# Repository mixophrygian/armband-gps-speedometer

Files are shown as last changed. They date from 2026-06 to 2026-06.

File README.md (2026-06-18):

# Armband GPS Speedometer

A kid-wearable armband speedometer built from Adafruit modules:

- GPS speed from an Adafruit Mini GPS PA1010D.
- mph (2 decimals) on a 4-digit seven-segment FeatherWing.
- A single 10-pixel NeoPixel lane on the armband (scoped down from the original
  four-lane plan; the armband only has room for ~10 pixels at 60 LED/m).
- Electronics pod hardwired to the lane, charged in place via USB-C through the
  Feather RP2040 (no pod-to-armband connector).

This v1 intentionally avoids a custom PCB. It uses existing Adafruit boards and
a small soldered perma-proto wiring hub inside the pod. Do not use a solderless
breadboard in the wearable.

## Project Structure

- `CIRCUITPY/code.py` - firmware to copy onto the Feather's CIRCUITPY drive.
- `CIRCUITPY/bringup/` - staged test programs to copy as `code.py` during
  bench bring-up.
- `CIRCUITPY/lib/requirements.txt` - CircuitPython libraries to copy into
  `CIRCUITPY/lib/`.
- `docs/bom.md` - purchase list and missing-part traps.
- `docs/bench-bringup.md` - detailed first-power, header, display, GPS,
  battery, and LED bring-up instructions.
- `docs/wiring.md` - electrical wiring, LED lane, and charging switch.
- `docs/assembly-checklist.md` - build phases from bench to final armband.
- `docs/3d-printing-guide.md` - primary enclosure walkthrough for the
  3D-printed pod (OpenSCAD, slicing for Bambu/Prusa, PETG, print order).
- `cad/enclosure.scad` - parametric 3D-printable enclosure (compact, battery
  under the stack for low CoG; ~69 x 61 x 41 mm).
- `cad/verify_fit.py` - optional CAD sanity check that redraws the plan view.
- `docs/test-plan.md` - bench and field acceptance tests.

## Firmware Defaults

- Units: mph.
- Display: speed in mph, 2 decimals (auto-drops to 1 decimal at/above 100 mph to fit 4 digits).
- LED lanes: 1.
- Pixels per lane: 10.
- Total pixels: 10.
- LED pin: Feather `D6`.
- LED brightness cap: `0.12`.
- LED lane wiring: single straight lane, no serpentine. (The firmware keeps the
  lane/`LANE_REVERSED` scaffolding so a future multi-lane build only needs the
  constants in `code.py` changed.)

## Install

Start with `docs/bench-bringup.md`; it walks through Feather setup, header
soldering, display installation, GPS, battery charging, and LED tests in order.

Quick install summary:

1. Install CircuitPython for the Adafruit Feather RP2040.
2. Copy `CIRCUITPY/code.py` to the CIRCUITPY drive as `code.py`.
3. Copy the required libraries from the Adafruit CircuitPython Library Bundle
   into `CIRCUITPY/lib/`: `adafruit_gps`, `adafruit_ht16k33`, and `neopixel`.
   If using `circup`, run `circup install -r CIRCUITPY/lib/requirements.txt`
   from this project folder after the Feather is mounted.
4. Wire the hardware following `docs/wiring.md`.
5. Run the bench tests in `docs/test-plan.md` before enclosing anything.

The firmware is designed to be useful during bring-up: it shows `8888` and a
blue sweep on boot, `----` plus an amber wave while waiting for GPS, speed
(2-decimal mph) plus a fixed-rate rainbow comet once GPS data is available, a
yellow pulse plus `----` if a fix goes stale/lost, and `Err` plus red flashing
for caught application errors after hardware setup.

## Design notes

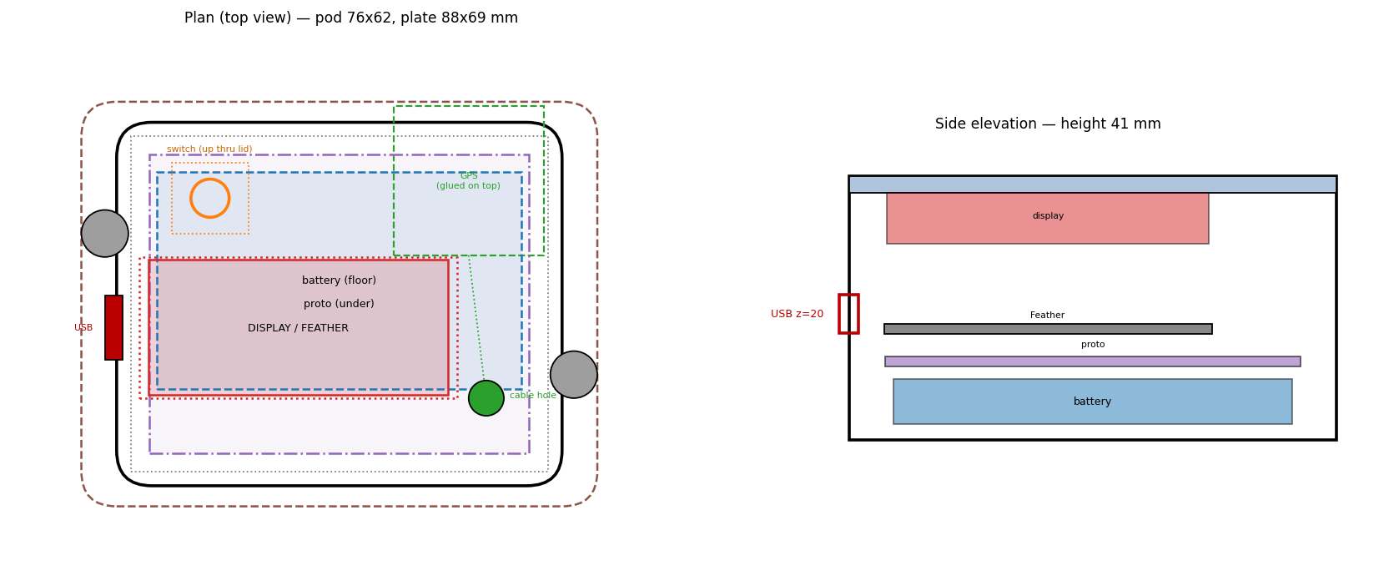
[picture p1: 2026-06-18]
cad/enclosure_plan.png

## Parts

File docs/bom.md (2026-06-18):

# Bill of Materials

This is the complete shopping list to build one armband speedometer from
scratch. Adafruit PIDs are given where a specific part matters; equivalents from
other vendors work unless a note says otherwise.

## Core Electronics

| Qty | Item | Notes |
| --- | --- | --- |
| 1 | [Adafruit Feather RP2040, PID 4884](https://www.adafruit.com/product/4884) | Main controller, USB-C, built-in LiPo charger, STEMMA QT. |
| 1 | [Adafruit Mini GPS PA1010D STEMMA QT, PID 4415](https://www.adafruit.com/product/4415) | Mount antenna facing skyward, not under the display/battery. |
| 1 | [Adafruit 0.56" 4-Digit 7-Segment FeatherWing, PID 3108 (red) or 3110 (yellow)](https://www.adafruit.com/product/3108) | Yellow (3110) is a bit more readable in bright daylight; red (3108) is fine indoors/dusk. Either works. |
| 1 | [Adafruit Lithium Ion Battery 3.7V 2000mAh, PID 2011](https://www.adafruit.com/product/2011) | Documented battery for this build and the 3D-printed enclosure. Adafruit-standard JST-PH polarity, built-in protection circuit, 60 x 36 x 7 mm. **Still verify connector polarity against the Feather silkscreen before first power (see bench-bringup.md Stage 6).** |
| 1 | [STEMMA QT / Qwiic JST-SH 4-pin I2C cable](https://www.adafruit.com/product/4399) | Connects the GPS to the Feather. |

## LED Lane

| Qty | Item | Notes |
| --- | --- | --- |
| 1 m | BTF-LIGHTING WS2812B Pure Gold Wire LED Strip, 60 LED/m, IP65, black PCB (Amazon) | The build uses 10 pixels (1 lane); 1 m (60 px) is plenty and leaves practice/splice scraps. WS2812B = standard NeoPixel chip; Pure Gold Wire = premium bond-wire variant (more reliable than the ECO line) for a wearable that takes abuse. See [LED Strip Details](#led-strip-details) below. |

## Headers & Power Conditioning

| Qty | Item | Notes |
| --- | --- | --- |
| 1 | Feather stacking headers | Must be stacking-style: female sockets on top, male tails extending below the Feather. Plain male strips won't give the under-side access the wiring needs. |
| 1+ | Male header strip | For the 7-segment FeatherWing legs. |
| 1 | 470 ohm resistor | NeoPixel data line. Anything 300-500 ohm is fine; a single 330 ohm works too. |
| 1 | 100uF electrolytic capacitor, 6.3V+ | Place near the first LED on the armband side, not the pod-side connector. 100uF (vs the usual ~1000uF) is deliberate here: LiPo source, brightness capped at 0.12, only 10 px = tiny transients. See wiring.md. |
| 1 | Miniature DPDT switch — 6mm-bushing **toggle** | One pole disables Feather `EN`; one pole cuts LED `BAT+`. The 3D enclosure cuts a 6.5mm round hole + guard ribs for the toggle. |

## Wiring & Assembly

| Qty | Item | Notes |
| --- | --- | --- |
| 1 | **Half-size** perma-proto (51 x 81 mm), or generic perfboard | Pod wiring hub. A quarter-size board doesn't have enough holes to seat the Feather — use half-size [PID 1609](https://www.adafruit.com/product/1609). Trim to ~65 x 51 to fit the enclosure (cut the length only; this board sizes the box). |
| Several | 26-30AWG silicone stranded wire | Red, black, and a third color for data. |
| Several | Heat-shrink tubing | Cover every soldered LED-strip joint. |
| Several | Standoffs/screws or foam tape | Secure boards inside the pod. |
| 1 | USB-C data cable | Must transfer data, not just charge. |

## Mechanical / Enclosure

| Qty | Item | Notes |
| --- | --- | --- |
| 1 | Armband | Any wearable band; the LED lane is semi-permanently attached to it. |
| 1 | 3D-printed pod/enclosure | Print the parametric enclosure in `cad/` using `docs/3d-printing-guide.md`. |
| Several | Velcro/hook-and-loop patches | Attach the pod to the armband. |
| Several | Flexible fabric/foam backing strips | Prevent sharp bends at LED solder joints. |
| Several | Cable tie points, thread, or adhesive | Strain relief at the pod-to-lane cable and LED lane ends. |

## Optional

| Qty | Item | Notes |
| --- | --- | --- |
| 1 | CR1220 coin cell | Improves GPS warm-start time. Not required. |

## Tools

| Item | Notes |
| --- | --- |
| Soldering iron + solder | Headers, LED-strip joints, and perma-proto wiring. |
| Multimeter | Required for the battery polarity check (bench-bringup.md Stage 6); also useful for continuity / short checks throughout. |
| Wire cutters / strippers | For the silicone wire and LED-strip leads. |

## LED Strip Details

**BTF-LIGHTING WS2812B Pure Gold Wire LED Strip Light**, 60 LED/m, IP65, black
PCB.

Build allocation:

- 10 pixels in service (1 lane x 10 pixels, lane ~167 mm / 6.6 in) — the armband
  only fits ~10 pixels at 60 LED/m
- The rest of a 1m strip (50 px) is practice scraps and splice spares

Why these specifics:

- **WS2812B chip** is the Adafruit `neopixel` library's reference part. No
  protocol surprises.
- **Pure Gold Wire** is BTF-LIGHTING's premium line. Pure-gold bond wires
  inside each LED package (vs aluminum or alloy on the ECO line) mean better
  corrosion resistance and longer-term reliability — relevant for a wearable
  that takes abuse.
- **IP65** silicone front coating adds sweat and scuff resistance. Sewing
  impact is negligible when sewing between LEDs.
- 60 LED/m at 10 px = ~167 mm lane length, fits the usable armband space and
  still gives room for a clean 5-7 px comet tail (8 px is the floor for a
  recognizable comet, so 10 has margin).
- 2000 mAh LiPo (PID 2011) runs the system many hours at brightness 0.12, far
  past the 90-minute runtime target, with only one lane driven.
- WS2812B is nominally 4-7 V; at 3.7 V LiPo it works but you may see slight
  color drift below ~3.4 V battery voltage. Acceptable at brightness 0.12.

Headroom: leftover strip gives you material to scale up later if you find more
armband real estate. To add pixels or lanes, change `PIXELS_PER_LANE` (and
`LANE_COUNT` / `LANE_REVERSED` for multiple lanes) in `CIRCUITPY/code.py`, and
update `PIXEL_COUNT` in `CIRCUITPY/bringup/05_one_lane_neopixel_test.py` to match
what you cut.

## Pre-Buy / Pre-Power Trap Check

- Battery polarity verified against the Feather silkscreen before plugging in,
  with a multimeter? (See `bench-bringup.md` Stage 6.)
- Stacking headers confirmed, not just plain male strips?
- 7-segment LED module is planned to plug into the Feather via stacking
  headers, not soldered directly to the Feather?
- USB-C cable is data-capable, not charge-only?
- Strain relief plan exists for the hardwired pod-to-lane cable (grommet clamp + service slack)?
- 470 ohm resistor and 100 uF cap for NeoPixel data and power?
- Enough heat shrink for all LED-lane and cable solder joints?
- Way to see the Feather charge LED after the pod is assembled?

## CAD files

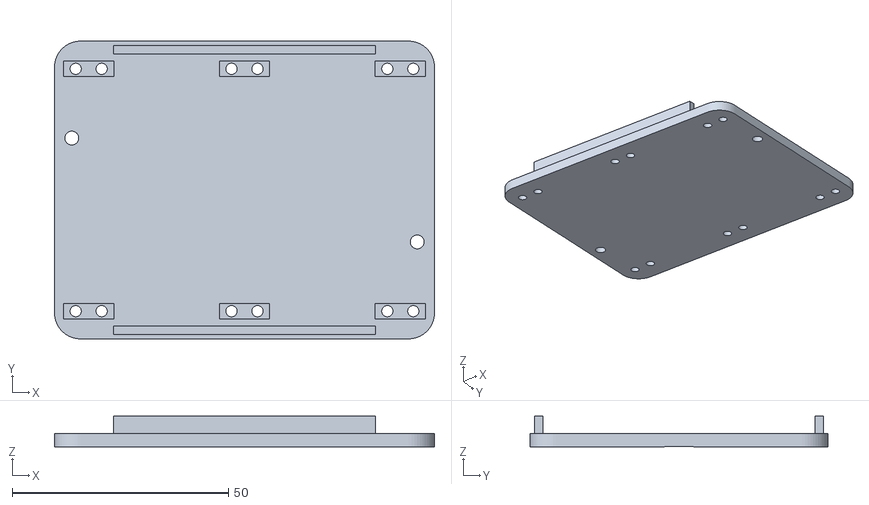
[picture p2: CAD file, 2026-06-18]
cad/base_plate.stl
87.8 x 68.8 x 7.06

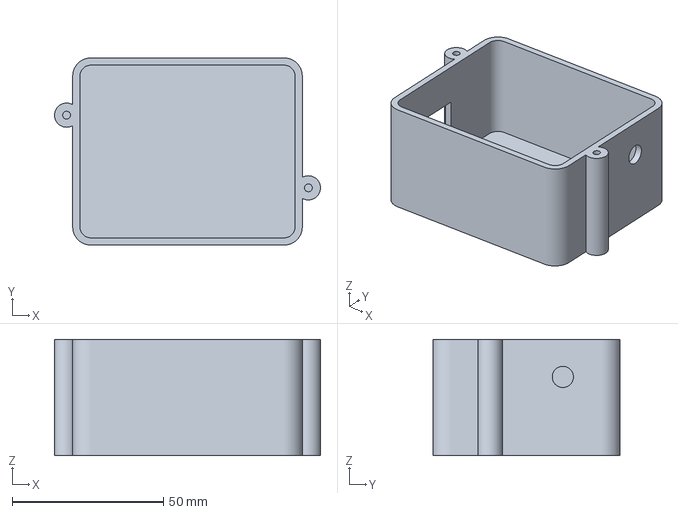
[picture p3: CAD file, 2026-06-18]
cad/base.3mf
87.8 x 61.8 x 38.4 mm

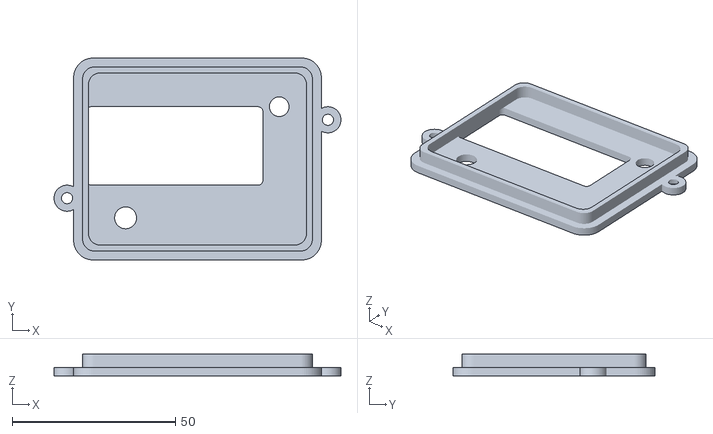
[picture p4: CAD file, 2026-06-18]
cad/lid_print.stl
87.8 x 61.8 x 6.60

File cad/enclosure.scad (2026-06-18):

// ============================================================================
//  Armband GPS Speedometer  —  Enclosure  (parametric)  —  v2: COMPACT
//  Battery sits on the floor UNDER the Feather (lowest centre of gravity).
//  All units are MILLIMETRES.
// ----------------------------------------------------------------------------
//  HOW TO USE (OpenSCAD):
//    F5 = preview | F6 = render | export STL via File > Export
//    Choose what to show with `part` below. Watch the console: it ECHOes the
//    battery clearance and the computed USB cutout height every render.
//
//  Vertical stack-up, floor -> sky (per your assembly):
//    floor -> [LiPo 7mm, flat on the floor] -> small gap -> PERMA-PROTO
//    (the Feather's header tails plug DOWN into it) -> Feather (sits close above
//    the proto) -> stacking-header gap -> FeatherWing backpack -> 7-seg display
//    (face seats against the lid window). display+Feather+proto hang from the lid
//    as ONE plugged-together unit; the battery sits on the floor beneath them.
//    The half-size perma-proto (51 x 81) is far too LONG for this box (81 > 64),
//    so it's TRIMMED to a small hub (proto_l/proto_w) that fits under the Feather.
//    Still MEASURE the assembled drop (display face -> proto bottom) to confirm
//    the height - that's the one number specs can't give you.
//
//  Companion guide: docs/3d-printing-guide.md
// ============================================================================


// ============================================================================
//  WHAT TO RENDER / EXPORT  (one part at a time; export each as its own STL)
// ============================================================================
part = "base";   // "base" | "lid" | "lid_print" | "baseplate" | "assembled"
mount_features = false;   // false = plain box (print this FIRST); true = add posts/cradle
$fn = 56;


// ============================================================================
//  MEASURED PARTS  —  values are your Adafruit spec sheets. (VERIFY) = confirm.
// ============================================================================

// --- Feather RP2040 + 7-seg FeatherWing stack (tallest assembly) ------------
feather_l        = 51.0;   // Feather 51.0 x 23.0 x 7.5
feather_w        = 23.0;
stack_hang       = 22.0;   // display face (at lid) -> Feather PCB bottom   << MEASURE
stack_envelope   = 27.0;   // display face -> tail tips, TRIMMED tails      << MEASURE
                           //   (was ~29 untrimmed; trimming flush after wiring is
                           //    what gets the box to ~41mm. Don't trim -> set back
                           //    to ~29 and bump inner_h ~4mm.)
feather_hole_dl  = 45.72;  // Feather mount-hole spacing, lengthwise  (VERIFY)
feather_hole_dw  = 17.78;  // Feather mount-hole spacing, widthwise   (VERIFY)
//  stack_hang and stack_envelope set the box HEIGHT and the USB cutout height,
//  and they depend on your stacking headers + how far the display stands off
//  the backpack + how you trim the tails -- none of which is on a spec sheet.
//  So MEASURE the assembled stack: face->Feather-PCB, and face->tail-tips.
//  Defaults here are a conservative estimate (display standoff ~10, header gap
//  ~8.5, tails ~7.5). Trimming the tails drops stack_envelope ~4mm; shave inner_h.

// --- 0.56" 4-digit 7-seg display --------------------------------------------
disp_pkg_l       = 50.0;   // display face length   (MEASURE your part)
disp_pkg_w       = 20.0;   // display face height    (you measured ~20, spec said 19)
disp_lip         = -2.0;   // NEGATIVE = clearance. -2 => window is 4mm bigger than the
                           //   display (2mm slop all round), so a recessed display
                           //   shows through with a small border and needs no precise
                           //   alignment. (Use 0 for a tight flush fit, +1 for a lip.)

// --- Mini GPS PA1010D (PID 4415)  25.5 x 25.4 x 8.2 -------------------------
gps_pcb_l        = 25.5;
gps_pcb_w        = 25.4;
gps_ant_l        = 11.0;   // ceramic patch antenna footprint  (VERIFY!)
gps_ant_w        = 11.0;   // antenna pokes UP through a hole this size

// --- LiPo 2000 mAh (PID 2011)  60 x 36 x 7,  lies FLAT on the floor ---------
batt_l           = 62.0;   // sets the box LENGTH
batt_w           = 37.0;
batt_h           = 7.0;

// --- Perma-proto wiring hub (TRIMMED from a half-size 51 x 81 board) ---------
//  Half-size because the quarter board hadn't enough holes. The hub must seat
//  the WHOLE Feather AND give spare rows to wire in the switch + LED strip, so
//  it's 65 x 51 (cut only the 81mm length down to 65; width left uncut at ~51).
//  This board now DRIVES the box length AND width - see inner_l / inner_w.
//  Reference dims for the fit check (verify_fit.py); the proto isn't printed.
proto_l          = 65.0;   // length, cut down from the stock 81
proto_w          = 51.0;   // width, left at the stock 51 (uncut)

// --- Ports (sizes; positions are in LAYOUT / GEOMETRY) ----------------------
usb_w            = 15.0;   // USB-C cutout width  - oversized for position slop
usb_h            = 10.0;   // USB-C cutout height - oversized in case usb_z is off
led_d            = 3.0;    // charge-LED hole / light pipe
grommet_d        = 7.0;    // armband-cable grommet
//  SWITCH: your part is a TOGGLE with a 6mm threaded bushing (6-pin DPDT),
//  NOT a slide switch. So the cutout is a ROUND hole + nut, not a slot.
//  Body ~13(w) x 12(deep) x 10(tall) sits INSIDE the box; lever sticks OUT.
switch_hole_d    = 6.7;   // 6mm thread + clearance (some are 1/4" -> try 6.7)


// ============================================================================
//  ENCLOSURE SHELL
// ============================================================================
inner_l   = 71;    // now set by the 65mm trimmed proto + end slack (the proto is
                   //   the longest thing in the box, not the 60mm battery)
inner_w   = 57;    // holds the 51mm-wide proto hub (centred) with margin
inner_h   = 36;    // ~41mm external. ASSUMES trimmed tails (see stack_envelope).
                   //   battery(7) + proto(2) + stack(25) + clearance(2).
//  L and W are now driven by the wiring hub: it has to seat the whole Feather
//  PLUS spare rows for the switch + LED-strip wiring, so it's 65 x 51.
//  Height is still set by the vertical stack + battery underneath (CoG stays low).

wall      = 2.4;
floor     = 2.4;
lid_th    = 2.6;
corner_r  = 6.0;

// --- lid <-> base mating -----------------------------------------------------
lip_h     = 4.0;
lip_th    = 1.8;
lip_clear = 0.35;

// --- EXTERNAL screw ears (2x, short ends) ------------------------------------
ear_r          = 4.0;
ear_overlap    = 2.0;
ear_pilot_d    = 2.6;
ear_clear_d    = 3.4;
ear_head_d     = 6.2;
ear_head_h     = 2.2;

// --- printed internal mounts (only when mount_features = true) ---------------
post_od        = 5.0;
post_pilot_d   = 2.2;
cradle_wall    = 2.0;
cradle_clear   = 1.0;
cradle_h       = 5.0;

// --- mounting baseplate (separate part: pod-size, sewn on, NO outboard flange)
show_mount     = true;   // draw the baseplate under the pod in the "assembled" view
plate_th       = 3.0;    // plate thickness
mount_radius   = 10000;  // DEFAULT FLAT for printing. A concave dish only touches
                         //   the bed at its rim and FAILS mid-print, so print the
                         //   plate flat and curve it to the brace by HEAT-FORMING
                         //   (heat gun till floppy, press onto the brace, hold to
                         //   cool). Only set a real radius (e.g. 120) if you truly
                         //   intend to print the curve with supports - not advised.
rail_h         = 4.0;    // locating rails the pod body nests between (anti-rock)
rail_t         = 2.0;
mount_screw_d  = 3.2;    // M3 up into the pod's end ears (uses the bottom pilots)
// thread anchors (sew the plate to the brace; no outboard flange needed):
anchor_hole_d  = 2.6;    // pair of these per anchor - sew up one, down the other
anchor_gap     = 6.0;    // hole spacing within a pair
groove_w       = 3.5;    // top groove the thread loop recesses into (pod won't pinch it)
groove_depth   = 1.4;    // leaves ~1.6mm bridge under the thread - don't go deeper
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

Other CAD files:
cad/base.stl

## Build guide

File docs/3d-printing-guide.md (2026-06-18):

# 3D Printing the Enclosure — From Zero

You've never printed anything, so this starts at the beginning and stays applied:
every step is tied to producing *this* box. The CAD file is `cad/enclosure.scad`.

## The one mental model to start with

A 3D print goes through **three** programs, not one. People new to it usually
think "CAD file → printer" and get stuck when the printer won't open their file.

1. **Design (CAD)** — you make the shape. That's `enclosure.scad`, opened in
   OpenSCAD. Output: an **STL** file (a watertight mesh of the shape).
2. **Slice** — separate software (Bambu Studio / Orca for the Bambu, PrusaSlicer
   for the Prusa) chops the STL into layers and writes machine instructions
   (**G-code / .3mf**) for *your specific printer and filament*.
3. **Print** — the printer runs the sliced file.

CAD knows nothing about your printer; the slicer is where printer- and
material-specific reality enters. Keep these three buckets separate in your head
and nothing about this will be confusing.

---

## Part 1 — OpenSCAD: see the box, then bend it to your parts

### Install and first render (Mac)

1. Download OpenSCAD from `openscad.org/downloads.html`, drag to Applications.
   (Free, ~40 MB. Windows/Linux builds are on the same page.)
2. Open `cad/enclosure.scad` in it. You'll see code on the left, a 3D view on
   the right.
3. Press **F5** (Preview — fast). The box appears. Drag to orbit, scroll to zoom.
4. At the top of the file, change `part = "assembled"` to `"base"`, press **F5**
   again. Now you see just the shell. Try `"lid"`. This is how you'll look at
   each piece.

That's the whole interaction loop: **edit a number → F5 → look**. OpenSCAD is
"CAD by typing," which sounds backwards but is exactly why it's the right tool
here — every dimension is a labeled variable, so making the box fit your parts is
editing numbers, not nudging geometry with a mouse.

### Design at a glance (the compact layout)

The box is **~69 × 61 × 41 mm** (plus two small screw ears on the ends). It's
**layered**: the display (centred) and GPS live at the lid; below them the column
is **battery → perma-proto → Feather → display**, with the battery flat on the
floor. That keeps the heaviest part lowest (low centre of gravity on your arm).
Reaching ~41 mm tall assumes you **trim the stacking-header tails** after wiring
and **trim the half-size perma-proto** to a small hub.

Two things to know:

- **GPS over the battery — mostly a non-issue here.** The battery overlaps the
  GPS in plan, but it sits ~28 mm *below* the lid-mounted antenna — about a patch
  antenna's near-field edge (λ/2π ≈ 30 mm at L1), with the GPS's own ground plane
  in between. That vertical gap does the real work, so expect at most a minor
  effect, not a meaningful sensitivity loss (and the battery is passive metal,
  not an RF noise source). On an arm-worn device the body under the antenna is a
  bigger lower-side RF load than the battery anyway. If you ever want more GPS
  margin, the real lever is a larger ground plane under the patch (copper tape to
  GND) — the PA1010D's weak point — not relocating the battery.
- **Want it even smaller?** Three levers: a shorter battery (the 60 mm cell sets
  the box length), trimming the stacking-header tails after wiring (shaves
  height), and cutting the perma-proto hub down to a small perfboard scrap so it
  tucks into dead space instead of needing its own room.

### How the file is built (so you can change it)

Open the file and read top to bottom — it's commented for exactly this. The
structure:

- **`MEASURED PARTS`** — real-world sizes (Feather, display, GPS antenna,
  battery). These came from the documented parts in `docs/bom.md`. Several
  are marked **`(VERIFY)`** — those are the ones I'm least sure of and you must
  confirm with calipers.
- **`ENCLOSURE SHELL`** — cavity size and wall thicknesses. The cavity
  (`inner_l/w/h`) is the empty space your parts live in; the outer size follows
  automatically.
- **`LAYOUT`** — an X/Y coordinate for each part (where it sits when you look
  down at the lid). These are the numbers you'll nudge after a dry-fit.
- **`GEOMETRY`** — the actual modeling. You rarely touch this.

The load-bearing idea: **you do not redraw anything to refit a part.** Measure
your real battery, type its true length into `batt_l`, press F5. If it now pokes
out of the cavity, bump `inner_w`. That feedback loop is the entire skill.

### Check the fit without printing

`cad/verify_fit.py` is an optional sanity check that mirrors the same numbers
and redraws the top-view plan (`cad/enclosure_plan.png`). Run it after you
change dimensions if you want a quick text/plan check before printing:

```
python3 cad/verify_fit.py
```

It already caught two layout bugs while I was setting this up (the GPS was
clipping the wall and overlapping the display stack). The printed parts and
actual dry-fit are still the real gate. If you change a number in the `.scad`,
update the matching value at the top of `verify_fit.py` before relying on its
output.

### Export the STL

For each part you want to print: set `part` (e.g. `"base"`), press **F6** (full
render — slower, makes it watertight), then **File → Export → Export as STL**.
For the lid, use **`part = "lid_print"`** — that's the lid pre-flipped so its
flat face is down, ready to slice. Export `base.stl` and `lid.stl`.

---

## Part 2 — The order that saves you a wasted print

Do **not** print the fully-featured version first. The internal mounts (printed
Feather posts, battery cradle, GPS retainer) depend on exact part positions you
haven't dry-fit yet. Sequence:

1. **Leave `mount_features = false`** (it already is). Export and print the
   **base only** first — it's the cheapest way to learn your printer and confirm
   the cavity swallows your boards.
2. **Dry-fit.** Drop your actual Feather stack, GPS, and battery into the printed
   base. Confirm they fit with room for wiring. Measure anything that's off with
   calipers and update the `.scad`.
3. **Print the lid** (`part = "lid_print"`), still plain. Check the display
   window lines up with the display face and the GPS antenna pokes through its
   hole. Adjust `stack_x/stack_y` and `gps_x/gps_y` if not.
4. **Now set `mount_features = true`**, tune the mount positions to your dry-fit,
   optionally re-run `verify_fit.py`, and reprint the lid. The base rarely needs
   a reprint.

This is the difference between "print once, glue everything, done in an evening"
(totally fine — you said so) and "print, dry-fit, refine." Start with #1
regardless; it's your real first print and a throwaway is cheap insurance.

A zero-cost version of the dry-fit: print the plan (`cad/enclosure_plan.png`) at
100% scale on paper, lay your parts on it, and check before you print anything.

---

## Part 3 — Slicing (Bambu and Prusa)

You have both a Bambu Lab and a Prusa — both are excellent and both run PETG out
of the box. Pick whichever's free; the steps are the same shape.

**Bambu Lab** → Bambu Studio (or Orca Slicer). **Prusa** → PrusaSlicer.

1. **Open the slicer, pick your exact printer model and nozzle** (almost always
   0.4 mm) from its dropdown. This is the step that makes the file printer-correct.
2. **Import** `base.stl` (and later `lid.stl`). It drops onto the virtual plate.
3. **Orientation** — this matters more than any setting:
   - **Base:** floor flat on the plate, opening up. Import orientation is already
     correct. The walls print upward; the USB/switch cutouts are holes in
     vertical walls and bridge fine with no support.
   - **Lid:** flat outer face **down** on the plate, mount features pointing up.
     If you exported with `part = "lid_print"` it's already oriented; otherwise
     rotate 180° about X. Printed this way the lid needs **no supports**.
4. **Filament:** select a **PETG** profile (e.g. "Generic PETG" or the Bambu/Prusa
   PETG preset). Don't use the default PLA profile.
5. **Key settings** (the presets are mostly right; sanity-check these):
   - Layer height **0.2 mm** (0.28 for the fit-test base if you want it faster).
   - Walls/perimeters **3+** — it's a wearable that gets dropped.
   - Infill **15–20%**, grid or gyroid.
   - Supports **off** (with the orientations above you don't need them).
   - **Brim 3–5 mm** — PETG can lift at the corners; a brim prevents it and peels
     off after. Cheap insurance on a ~70 mm-long flat part.
6. **Slice**, eyeball the layer preview, then **send to the printer** (Bambu: over
   network/SD; Prusa: export G-code to SD/USB).

---

## Part 4 — PETG and the actual print

**Why PETG, briefly:** the default everyone starts with is PLA, which goes soft
around 55–60 °C. A car in summer sun hits that and your box deforms. PETG stays
solid to ~80 °C and shrugs off sweat, UV, and impact — the right call for an
outdoor kid's wearable. It's the second most common filament after PLA: every
spool vendor stocks it, it's cheap, and both your printers handle it natively.
(ABS/ASA is even tougher but warps and smells while printing — not worth it here.)

**PETG quirks vs PLA, so they don't surprise you:**
- Hotter: nozzle ~235–245 °C, bed ~70–85 °C (let the preset set it).
- Likes a **dry** spool — if it's been open in humid air for months, dry it first
  (printer's built-in dry cycle, or a food dehydrator) or you'll get stringing.
- Sticks to smooth PEI build plates *really* well — a thin swipe of glue stick
  acts as a **release** agent so you don't chip the plate prying parts off.
- A little **stringing** (fine hairs) is normal; they brush off.

**Running it:**
1. Make sure the build plate is clean (IPA wipe) and loaded with PETG.
2. Start the print. **Watch the first layer** — that's where 90% of failures
   happen. It should look like flat, slightly-squished lines fully stuck down,
   no gaps and not see-through. If it's not sticking, stop and re-level / re-set
   Z-offset (your printer's wizard does this).
3. The base is ~1–2 hours; the lid similar. Let the bed cool before removing —
   PETG often pops off on its own as the plate cools.
4. **Post-processing:** the holes may have a thin "bridge" skin or whiskers — open
   them with a hobby knife or a quick twist of a drill bit by hand. Self-tapping
   M3 screws cut their own threads into the bosses; drive slowly so you don't
   strip them.

---

## Print day — taking files to a shared / unknown machine

You don't control the machine, so make the files universal and carry a cheat-sheet.

### Before you leave the house

1. **Plug in your measured numbers and optionally re-run the check.** Open `enclosure.scad`,
   set the `MEASURE`/`VERIFY` values to your real calipered numbers — at minimum
   `stack_hang`, `stack_envelope` (the assembled display→Feather→tail-tips drop),
   `gps_ant_l/w`, and the switch body height. `python3 cad/verify_fit.py` can
   catch obvious layout mistakes, but dry-fitting the real boards is the gate.
2. **Export three STLs.** In OpenSCAD set `part` to each of `base`, `lid_print`,
   and `baseplate`; press **F6**, then **File → Export → Export as STL**.
   - Leave `mount_features = false` for this first round (plain box).
   - For the baseplate's first print, set **`mount_radius = 1000`** so it prints
     **flat** — far easier than a curved plate, and a 3 mm PETG plate pulled down
     by 12 sew/rivet points will conform to a "somewhat curved" stiff brace. Only
     model the real curve if the flat one visibly rocks on the brace.
3. **STL is universal** — it loads in any slicer (Bambu Studio, PrusaSlicer, Cura,
   Orca). You don't need to know the machine in advance.

### What to physically bring

- USB stick with the **3 STLs**, plus a cloud/email copy as backup.
- The **actual electronics** — assembled Feather/display stack, battery, switch —
  to **dry-fit into the base on the spot**. This is the whole point of going: find
  out it fits (or doesn't) before you leave.
- **Calipers.**
- A **PETG spool** if the shop lets you load your own filament; otherwise ask what
  they have. PLA is fine for the *throwaway test base* only — get PETG for the
  real build (see Part 4 for why).
- This guide.

### At the machine (any slicer)

1. Import the STL.
2. Select **the machine's own printer profile** (ask staff which model) and a
   **0.4 mm nozzle**.
3. Filament: **PETG** if available.
4. **Orientation** (this is the part people get wrong):

   | Part | Sits on the bed as | Support |
   | --- | --- | --- |
   | `base` | floor down, opening up (as exported) | none |
   | `lid` (use `lid_print`) | flat outer face down, features up | none |
   | `baseplate` (flat) | flat bottom down, rails up | none |

5. Settings: **0.2 mm** layer, **3** perimeters, **15–20 %** infill, **supports
   OFF**, **brim 5 mm**.
6. Slice, eyeball the preview, and **print the `base` first**.

### Order on the day

Print the **base first** → **dry-fit your boards into it right there** → if it's
good, print the **lid** and **baseplate** in the same session. If something's off,
note exactly what, and it's a one-variable fix back home rather than a bad full
set of prints. Bringing the electronics is what turns one trip into a finished
fit instead of a guess.

---

## When you're back at it

The realistic path: install OpenSCAD, render the box, **print the plain base
first** as your learning print, dry-fit your boards, then refine. Everything
above is reference you can come back to. When you hit the dry-fit step and the
numbers need changing, that's the moment to come back and we'll tune the layout
together.

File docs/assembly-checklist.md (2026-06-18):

# Assembly Checklist

## 1. Pre-Purchase Check

- [ ] All core boards are in the cart: Feather RP2040, PA1010D GPS, 7-segment FeatherWing.
- [ ] NeoPixel strip quantity is 1 m; the build only uses ~10 pixels (~167 mm).
- [ ] LiPo is Adafruit-compatible JST-PH polarity.
- [ ] STEMMA QT cable is present for the GPS.
- [ ] 26-30 AWG silicone wire (red/black/data color) for the hardwired pod-to-lane cable is present. (v2 uses no pod-to-armband connector; the JST-PH 6-pin pairs are spares.)
- [ ] 6mm-bushing DPDT toggle switch is present.
- [ ] Resistor, capacitor, silicone wire, heat shrink, Velcro, foam, and USB-C cable are present.

## 2. Bench Bring-Up

- [ ] Follow `docs/bench-bringup.md` before mounting anything to the armband.
- [ ] Feather alone boots over USB and prints from `01_feather_serial.py`.
- [ ] CircuitPython libraries are installed in `CIRCUITPY/lib/`.
- [ ] 7-segment LED module is soldered to the display FeatherWing in the correct orientation.
- [ ] Display FeatherWing male headers are soldered straight.
- [ ] Feather stacking headers are soldered straight.
- [ ] I2C scan sees display address `0x70`.
- [ ] Display test shows `8888` and a counter.
- [ ] GPS is connected by STEMMA QT; I2C scan sees GPS address `0x10`.
- [ ] GPS test reports fix/satellites outdoors.
- [ ] LiPo charges over Feather USB-C and boots the Feather on battery.
- [ ] The 10-pixel NeoPixel lane works on the bench before bonding to fabric.

## 3. LED Lane Prototype (single 10-pixel lane)

- [ ] Cut one 10-pixel lane.
- [ ] Note the data direction arrow before sewing or bonding; wire into `DIN`.
- [ ] Solder `+`, `GND`, and data (through the 470 ohm resistor) to the `DIN` end.
- [ ] Heat-shrink every exposed LED lane joint.
- [ ] Verify all 10 pixels animate.

## 4. Switch And Charging Test

- [ ] Wire DPDT switch on the bench before final pod assembly.
- [ ] OFF position grounds Feather `EN`.
- [ ] OFF position disconnects LED `+` from Feather `BAT`.
- [ ] ON position leaves Feather `EN` floating and connects LED `+` to Feather `BAT`.
- [ ] LiPo charges from USB-C while the battery remains plugged into the Feather.
- [ ] Charge status LED is visible enough for the final pod design.

## 5. Pod And Armband Dry Fit

- [ ] GPS antenna is skyward and unobstructed.
- [ ] Display is readable while worn.
- [ ] Switch is reachable but not easy to bump accidentally.
- [ ] USB-C is reachable without opening the pod.
- [ ] LiPo is padded and isolated from solder joints.
- [ ] Hardwired pod-to-lane cable is strain-relieved at the pod grommet, with coiled service slack so the lid can lift.
- [ ] Pod Velcros on and off the armband cleanly.
  - Charging method is **finalized: charge-in-place via USB-C** — the whole unit
    stays on the armband while charging, so the pod does not need to come off for
    power. The USB-C port just needs to be reachable through a box opening.

## 6. Final Assembly

- [ ] Permanent wiring is soldered on the proto board. See `proto-soldering.md`
      for the step-by-step solder order (can be done before choosing an enclosure).
- [ ] All exposed joints are heat-shrunk or insulated.
- [ ] Boards are secured with standoffs, screws, or foam tape.
- [ ] Pod corners are rounded or padded.
- [ ] Armband has no scratchy solder, sharp plastic, or loose wire ends.
- [ ] Final firmware settings match the actual pixel count and lane orientation.

## 7. Field Test

- [ ] Outdoor GPS lock succeeds before running.
- [ ] Speed display is readable during movement.
- [ ] LEDs show no-fix, normal, stale/lost, and error patterns.
- [ ] Compare speed against a phone/watch.
- [ ] Check comfort after 10 minutes.
- [ ] Check battery warmth and runtime.

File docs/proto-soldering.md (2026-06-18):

# Proto Board Soldering Walkthrough

This is the bridge between the bench bring-up and the enclosure. You finished
`bench-bringup.md` with everything working on a breadboard with jumper wires.
This doc moves that exact circuit onto a **perma-proto board** as a permanent
wiring hub, using **long wires** so the box can be decided later. Nothing here
forces an enclosure decision.

Read this all the way through before heating the iron.

## The one big idea: a perma-proto is a soldered breadboard

An Adafruit perma-proto has the **same pre-connected layout as a breadboard**:

- Each **row** (the 5 holes on one side of the center channel) is one connected
  node. The two halves of a row are separated by the center channel.
- The strips along the long edges are the `+` and `-` **power rails**.

So the move is simple: **recreate the wiring you already had on the breadboard —
same rows, same rails — and solder it down.** Parts in the same row are already
joined; you only add a wire when two *different* rows (or a row and a rail) need
to connect.

This doc assumes the **half-size** perma-proto with `+`/`-` rails you have. (If
you ever use a plain perfboard with no rails, see the footnote at the end — you
build the rails yourself.)

## What changes and what doesn't

| Part | On the breadboard now | After this doc |
| --- | --- | --- |
| Feather + display stack | tails in breadboard | tails soldered into the perma-proto |
| 470 ohm resistor | breadboard | soldered to the perma-proto |
| DPDT switch | jumpers to breadboard | long wires soldered to the perma-proto |
| LED lane | jumpers to breadboard | hardwired 3-conductor cable soldered to the perma-proto |
| GPS (PA1010D) | STEMMA QT plug | **unchanged — stays a plug into the Feather** |
| LiPo battery | JST-PH plug | **unchanged — stays a plug into the Feather** |
| 100 uF capacitor | (you never installed one) | **optional; if added, on the armband — see `wiring.md`** |

The GPS and battery never touch the perma-proto. They plug into the Feather's own
connectors and stay fully detachable, so the GPS can live outside the box.

## Assumptions (tell me if any are wrong)

1. **Board:** Adafruit perma-proto, half-size, with `+`/`-` rails.
2. **Feather attach:** the Feather's stacking-header **tails are soldered
   directly into the perma-proto rows.** If you want it removable, solder female
   headers in and plug the Feather into those instead — but that adds ~8 mm of
   height, tight in the pod. This doc assumes direct solder.
3. You are using the **470 ohm** data resistor from `bom.md`.

## Tools and materials

- Soldering iron (~350 C / 650 F) with a clean, tinned tip
- Rosin-core solder (60/40 leaded is easiest to learn on; lead-free is fine)
- Flush cutters and wire strippers
- **Stranded silicone wire, 22-26 AWG**, in at least three colors (red `+`,
  black `GND`, a third for data) — cut these **long**, trim later
- A couple of short jumper wires (for row-to-rail hops)
- Heat-shrink tubing + a heat source
- Helping hands or a board vise
- **Multimeter** with continuity (beep) mode — not optional for this

## Soldering primer (read if you've never done this)

- **A good joint:** touch the iron to the pad *and* the lead at the same time for
  ~1 second, then feed solder into the joint (not onto the iron tip). It flows
  and forms a small shiny cone. Solder away, then iron away. ~1-2 seconds total.
- **Cold joint** (dull, blobby, ball sitting on top): reheat, add a touch of
  solder/flux.
- **Bridge** (solder accidentally spanning a row into the next row): wick it off
  or drag it away with the hot tip. Eyeball the underside every few joints.
- Remember the row is *already* connected end to end — you don't need to solder
  every hole in a row, just the one your part/wire sits in.

## The node map (your wiring target)

Six nodes. On a perma-proto a "node" is **a row or a rail**. Keep this next to
you; the final test checks against it.

| Node | What lands on it |
| --- | --- |
| **D6** | Feather `D6` tail + resistor leg 1 (same row = joined) |
| **DATA** | resistor leg 2 + LED cable **data** wire (out to lane `DIN`) |
| **EN** | Feather `EN` tail + switch **pole 1 common** wire |
| **BAT** | Feather `BAT` tail + switch **pole 2 ON-throw** wire |
| **LEDV** | switch **pole 2 common** wire + LED cable **`+`** wire |
| **GND rail** | Feather `GND` tail + switch **pole 1 OFF-throw** wire + LED cable **`GND`** wire |

Switch lugs left **empty**: pole 1 ON-throw and pole 2 OFF-throw.

```text
 row D6   : Feather D6  ===[ 470R ]=== row DATA --> LED cable data --> lane DIN
 row EN   : Feather EN  ------------------------- switch pole1 COMMON
 row BAT  : Feather BAT ------------------------- switch pole2 ON
 row LEDV : switch pole2 COMMON --+--- LED cable + --> lane +
 - rail   : Feather GND --+--- switch pole1 OFF
                          +--- LED cable GND --> lane GND
```

---

## Stage 0: Plan the layout (no soldering)

1. Unplug USB and the LiPo. Set the GPS aside.
2. Dry-fit the Feather (display still stacked) so its two header rows **straddle
   the center channel**, tails into the holes — exactly like on the breadboard.
3. Find the rows its key pins land in: **`D6`, `BAT`, `EN`, `GND`** (the Feather
   pins are silkscreened — `6` is D6). Note them.
4. Pick the **`-` rail** nearest the Feather `GND` row as your GND bus.
5. Pick an empty row next to `D6` for **DATA**, and an empty row for **LEDV**.
6. Plan where the long wires exit (switch wires + the 3-wire LED cable) — toward
   where the cable will leave the future box.
7. Lift the Feather back out. Low-profile parts go in first while the board is
   clear and flat.

Success: you can point to the rows for D6, DATA, EN, BAT, LEDV, and the `-` rail.

## Stage 1: Solder the low-profile parts (Feather out)

1. **Resistor:** bend its legs flat. Put leg 1 in any hole of the **D6 row** and
   leg 2 in the **DATA row**. Solder both, flush-cut the leftover legs. (No
   polarity.) Because the D6 row is one node, the resistor is now joined to
   wherever the D6 tail will land — no extra wire needed.
2. **GND row -> `-` rail jumper:** short wire from any hole of the Feather `GND`
   row to the `-` rail. Solder both ends. Now Feather ground reaches the bus.

Success: resistor bridges D6 row -> DATA row; the GND row beeps to the `-` rail.

## Stage 2: Solder the Feather into the board

1. Reseat the Feather, tails through their rows, straddling the center channel.
   Confirm `D6` lands on the resistor's row and `GND` on the bussed row.
2. **Tack one corner tail,** check the Feather is flat and square, reheat/nudge
   if tilted.
3. Solder the rest of the tails one at a time. At minimum **`D6`, `BAT`, `EN`,
   `GND` plus the four corners** for strength; soldering all that reach holes is
   sturdier. Watch for bridges into neighboring rows.

Success: Feather is rigid, no tilt, no bridged rows.

> The display is stacked on top; soldering the tails underneath won't hurt it.
> Don't dwell on any one pin more than a couple seconds.

## Stage 3: Solder the long switch wires

Cut four wires **long** (reach the switch wherever it lands in the box, plus a
service loop). If the switch already has pigtails from the bench test, solder
their free ends to the board instead.

1. **Pole 1 common -> EN row.**
2. **Pole 1 OFF-throw -> `-` rail.**
3. **Pole 2 common -> LEDV row.**
4. **Pole 2 ON-throw -> BAT row.**
5. Leave pole 1 ON-throw and pole 2 OFF-throw **empty.**
6. Heat-shrink each switch-lug joint so adjacent lugs can't touch.

If unsure which lug is which, redo the common/throw multimeter check from
`bench-bringup.md` Stage 8 before soldering.

Success: four wires run board->switch; two lugs empty; lug joints insulated.

## Stage 4: Solder the hardwired LED cable

The 3-conductor cable that leaves the pod and runs to the armband lane. Cut it
**long** with extra service slack. Colors: red `+`, black `GND`, third = data.

1. **Data wire:** **DATA row** -> lane **`DIN`** pad.
2. **`+` wire:** **LEDV row** (shares the row with the switch pole-2 common wire)
   -> lane **`+`** pad.
3. **`GND` wire:** **`-` rail** -> lane **`GND`** pad.
4. Heat-shrink every joint at the lane end. Strain-relieve the cable at the lane
   end now; the pod-wall strain relief waits for the enclosure.

> A 100 uF cap is optional for this build (you've run fine without one). If you
> add it, it goes across the lane's `+` and `GND` **at the armband**, polarity
> observed — see `wiring.md`. Not on this board.

Success: three wires run board->lane; lane joints insulated and strain-relieved.

## Stage 5: Continuity test before any power

Multimeter on continuity. LiPo and USB disconnected. Check every node connects
and nothing shorts:

- D6 -> resistor -> DATA -> LED data wire: ~470 ohm end to end (not a beep).
- Feather GND -> `-` rail -> switch pole-1 OFF-throw -> LED GND wire: all beep.
- Feather BAT -> switch pole-2 ON-throw: beep.
- Feather EN -> switch pole-1 common: beep.
- LEDV (switch pole-2 common) -> LED `+` wire: beep.
- **Critical short check:** BAT to GND must **NOT** beep (switch ON or OFF).
  LEDV to GND must not beep. D6 to GND must not beep.

Then exercise the switch:
- **ON:** EN to GND should **not** beep (EN floats high = Feather on); BAT to
  LEDV **should** beep (LED power connected).
- **OFF:** EN to GND **should** beep (Feather disabled); BAT to LEDV should
  **not** beep (LED power cut).

Success: every node connects, no power-to-ground short, switch flips both
behaviors. **Do not power up until this passes.**

## Stage 6: Power-up smoke test

1. Plug the GPS back into the Feather's STEMMA QT.
2. Plug in the LiPo, then USB.
3. Same as `bench-bringup.md` Stage 9 — confirm the boot sweep, then the
   no-fix / normal / stale LED states and the mph display behave exactly as they
   did on the breadboard. Take it outside for a fix.

If something changed from the breadboard:
- A state that worked before now fails -> suspect a cold joint or a bridge on
  that node. Reflow it and re-run the Stage 5 checks.
- Nothing lights / no display -> recheck the GND rail jumper and Feather GND.
- LEDs dead but display fine -> recheck LEDV/switch pole 2 and the data path.

Success: identical behavior to the end of bench bring-up, now on a solid board.

## What is still deferred to the enclosure

You have committed only the *electrical* build. Still open, and fine to leave so:

- Where the switch bushing pokes through a wall (mount it from inside later).
- Where the LED cable exits (a slit/grommet, cut later).
- Mounting the board stack and padding the LiPo.
- The USB-C and GPS openings.
- Cable strain relief at the pod wall.

Keep all the long wires coiled with service loops until then.

---

## Footnote: plain perfboard (no rails)

If you ever build this on a plain perfboard instead, the difference is that
**nothing is pre-connected** — every hole is isolated. Then:

- Build the **GND bus yourself**: lay a bare wire across a line of holes and
  solder each, and use that everywhere this doc says "`-` rail."
- Each node that this doc gets "for free" from a shared row must be made by a
  short wire on the underside (e.g. D6 blob -> resistor leg). The Feather's
  soldered pins give you an underside solder blob per pin to wire from; more than
  one wire can share one blob.

Everything else — the node map, the stage order, the tests — is identical.

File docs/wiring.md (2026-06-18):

# Wiring Guide

## System Layout

```text
Pod, charged in place via USB-C
+----------------------------------------------------+
| GPS antenna up        7-segment display readable   |
| Feather RP2040 + LiPo + perma-proto + DPDT switch  |
| USB-C cutout + charge LED window                   |
+--- hardwired 3-conductor cable (+, GND, data) -----+
                     |  (continuous, no connector)
Armband, semi-permanent LED
+----------------------------------------------------+
| lane 1: 10 pixels  ->                              |
+----------------------------------------------------+
```

> Note: this v2 **hardwires** the pod to the armband lane — three continuous
> conductors (`+`, `GND`, data), no pod-to-armband connector. The pod is charged
> **in place via USB-C** and never separates from the armband for daily use, so
> the connector that earlier plans used (to unplug the pod for charging) was
> dropped: fewer parts, fewer joints, and no non-locking connector to pop apart
> on a kid's arm. The trade-off is that pod and armband are now one captive unit
> — separating them later means desoldering. See `3d-printing-guide.md` for the
> documented 3D-printed pod.

This v2 is a **single 10-pixel lane** — the armband only has room for about 10
pixels at 60 LED/m. That removes the serpentine wiring and the lane-to-lane data
joints the original four-lane plan needed. The firmware still keeps the lane
scaffolding so it is one constant change away from multi-lane:

```python
LANE_COUNT = 1
PIXELS_PER_LANE = 10
LANE_REVERSED = (False,)   # single lane: no reversal
```

## I2C Devices

Use the Feather RP2040's default I2C/STEMMA QT bus:

| Device | Connection |
| --- | --- |
| 7-segment FeatherWing | Plugged into Feather headers; uses I2C address `0x70`. |
| Mini GPS PA1010D | STEMMA QT cable to the same I2C bus. |

Mount the GPS with its ceramic patch antenna facing skyward. Do not place the
display, LiPo, switch, or copper wiring over the GPS antenna.

## Header Stack And Remaining Connections

The display FeatherWing should not be soldered directly to the Feather. The
intended stack is:

```text
7-segment FeatherWing with male headers
        plugs into
Feather stacking-header sockets
        soldered to
Feather RP2040 through-holes
        with male tails available underneath
```

Those stacking-header tails are how the pod wiring gets access to Feather pins
after the display is installed. The through-holes are occupied, but not lost;
they now continue through the header pins.

Use these connection sources:

| Need | Connection source |
| --- | --- |
| LiPo battery | Feather JST-PH battery connector, not through-holes |
| Charging | Feather USB-C connector |
| GPS | Feather STEMMA QT connector, or `SDA`/`SCL` tails if the connector is blocked |
| LED data | `D6` stacking-header tail to perma-proto resistor |
| LED power | `BAT` stacking-header tail to DPDT switch/perma-proto |
| LED ground | `GND` stacking-header tail to perma-proto |
| Power switch | `EN` stacking-header tail to switch, then `GND` when off |

For v1, the cleanest layout is usually a small perma-proto next to or under the
Feather stack, with short wires from the accessible bottom tails. If you can make
a tidy underside proto mount without blocking USB-C, the tails can also be
soldered into that proto board.

## Pod-To-Armband Cable (Hardwired, No Connector)

The pod and the armband lane are joined by a **single hardwired 3-conductor
cable** — no connector. Earlier plans used a JST-PH 6-pin pair so the pod could
be unplugged for charging; charging now happens **in place via USB-C**, so that
reason is gone and the connector was dropped. The result is fewer parts, half
the solder joints, and no non-locking connector that can pop apart on a kid's
arm.

The three conductors:

| Conductor | From (pod) | To (armband) |
| --- | --- | --- |
| LED `+` | Feather `BAT` via the DPDT switch | lane `+` pad |
| LED data | Feather `D6` via the 470 ohm resistor | lane `DIN` pad |
| LED `GND` | Feather `GND` | lane `GND` pad |

Use 26-30 AWG silicone stranded wire with a consistent color convention (red
`+`, black `GND`, a third color for data). Run all three as one bundled cable
out of the pod to the lane.

> Trade-off you've accepted: with no connector, pod and armband are one captive
> unit. To separate them for service you desolder at the perma-proto. Leave a
> little extra cable length (service slack) so the pod can open and the lid lift
> without tugging the lane's solder joints — see `3d-printing-guide.md`.

Strain relief still matters, just at different points: clamp the cable where it
exits the pod (grommet) and immobilize it at the lane end so arm motion flexes
the cable, never the solder pads.

## NeoPixel Lane

Use one 10-pixel cut from the BTF-LIGHTING WS2812B strip (Pure Gold Wire,
60 LED/m, IP65). Only 10 pixels go into the build; the rest of the strip is
practice scraps and spares.

Data path:

```text
Feather D6
  -> 470 ohm resistor (330 ohm works; 300-500 ohm acceptable)
  -> hardwired data conductor
  -> lane DIN -> lane DOUT (unused)
```

Power:

```text
Feather BAT -> DPDT switch -> hardwired + conductor -> LED lane +
Feather GND ------------------------------------------> LED lane GND
```

A single lane needs no lane-to-lane chaining: `+`, `GND`, and data land on the
one lane's DIN end and that's it. Keep the LED ground tied to Feather ground.

Place the 100 uF capacitor **on the armband side**, across LED `+` and `GND`
at or near the lane's DIN end. Observe capacitor polarity. (Earlier
versions of this doc put the cap pod-side; armband-side is better practice
because the cap's job is to absorb switching transients at the LED input, and
a pod-side cap sees those transients only after the connector and cable have
already dropped some of them. If you'd rather not put a cap on the armband
for mechanical reasons, the pod-side placement still helps and is acceptable.)

The NeoPixel guides recommend ~1000 uF, but this build uses **100 uF**
intentionally: the strip is powered directly from a LiPo (no switching-supply
turn-on spike to absorb) at a 0.12 brightness cap across only 10 pixels, so the
transient current is tiny. 100 uF is more than ample here; parallel a second
100 uF for ~200 uF if you ever raise the brightness or pixel count. Do not
bother sourcing a 1000 uF part for this design.

## DPDT Power Switch

Use one DPDT switch so OFF disables both the Feather regulator and LED battery
power while leaving the LiPo plugged into the Feather for USB-C charging.

| Switch pole | Common lug | ON throw | OFF throw |
| --- | --- | --- | --- |
| Feather enable | Feather `EN` | Not connected | Feather `GND` |
| LED power | LED `+` (hardwired conductor) | Feather `BAT` | Not connected |

The Feather `EN` pin is pulled up internally. Grounding `EN` turns off the 3.3V
regulator. The second pole prevents the LED strip from staying connected to the
LiPo when the wearable is off.

The LiPo stays plugged into the Feather JST-PH battery connector at all times.
Charging happens through Feather USB-C. The enclosure needs a USB-C opening and
a small window or light pipe for the charge status LED.

## Practical Wearable Notes

- Never let the LiPo bend, crush, rub against solder joints, or sit under screw
  heads.
- Cover exposed LED strip pads with heat shrink or flexible sealant.
- Strain-relieve the hardwired cable where it exits the pod (clamp at the
  grommet) and where it meets the lane, so arm motion flexes the cable, never
  the solder pads. Leave a little service slack so the pod can open without
  tugging joints.
- Do not sharply bend the LED strip at solder pads. Let fabric/foam flex around
  the strip segments.
- Keep a common ground between Feather, GPS/display I2C, and LEDs.

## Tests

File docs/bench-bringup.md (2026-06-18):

# Bench Bring-Up Guide

This guide gets the electronics working in stages before anything is mounted to
the armband. The goal is to find mistakes while the hardware is still easy to
hold, inspect, and rework.

Do not plug in the LiPo while soldering. Do not power the Feather from USB while
adding/removing boards. Unplug power first, change hardware, inspect, then power
again.

## What You Need On The Bench

- Feather RP2040
- 7-segment FeatherWing
- Feather stacking headers
- Male header strips for the 7-segment FeatherWing
- PA1010D GPS
- STEMMA QT cable
- USB-C data cable
- Computer with a serial console editor such as Mu, Thonny, or the CircuitPython serial console
  - On macOS, the reliable console is `screen /dev/cu.usbmodem101 115200` (baud 115200).
    The board only streams once DTR is asserted; `screen` does this, but the VS Code
    Serial Monitor extension does not, so it shows nothing. Quit screen with
    `Ctrl-A` then `K` then `y`. If a port is stuck/busy, run `pkill screen`.
    The exact device name may differ; list ports with `ls /dev/cu.usbmodem*`.
- Soldering iron, solder, flush cutters, and something to hold headers straight
- Later stages: NeoPixel strip (BTF-LIGHTING WS2812B Pure Gold Wire, 60 LED/m, IP65 — 1 m is plenty), 470 ohm resistor, 100uF capacitor (see wiring.md for why 100uF instead of the usual 1000uF), 26-30 AWG silicone wire for the hardwired pod-to-lane cable (v2 has no pod-to-armband connector), LiPo (Adafruit 2000 mAh PID 2011, standard polarity), and a 6mm-bushing DPDT toggle switch
- Multimeter — required at Stage 6 for battery polarity verification; also useful throughout for continuity and short checks

## Stage 1: Feather Alone

1. Leave the display, GPS, LEDs, switch, and LiPo disconnected.
2. Plug the Feather into the computer with a USB-C data cable.
3. If a drive named `CIRCUITPY` appears, CircuitPython is already installed.
4. If no `CIRCUITPY` drive appears, install CircuitPython:
   - Unplug USB.
   - Hold the Feather `BOOTSEL` button while plugging USB back in.
   - A drive named `RPI-RP2` should appear.
   - Download the Feather RP2040 CircuitPython UF2 from CircuitPython.org.
   - Drag the UF2 file onto `RPI-RP2`.
   - The board should reboot and appear as `CIRCUITPY`.
5. Copy `CIRCUITPY/bringup/01_feather_serial.py` from this repo to the mounted board as `code.py`.
6. Open the serial console.

Success: the console prints `Feather RP2040 alive:` once per second. If your
board exposes `board.LED`, that LED also blinks.

If it fails:
- Try another USB-C cable; many cables are charge-only.
- Confirm the drive is named `CIRCUITPY`, not `RPI-RP2`.
- Reinstall CircuitPython if the drive contents look strange.

## Stage 2: Install Libraries

Install these libraries into the board's `CIRCUITPY/lib/` folder:

- `adafruit_gps`
- `adafruit_ht16k33`
- `neopixel`

Manual method:
1. Download the Adafruit CircuitPython Library Bundle that matches your major
   CircuitPython version.
2. Open the bundle's `lib/` folder.
3. Copy `adafruit_gps.mpy`, the `adafruit_ht16k33/` folder, and `neopixel.mpy`
   into `CIRCUITPY/lib/`.

`circup` method:

```sh
circup install -r CIRCUITPY/lib/requirements.txt
```

Run that command from this project folder while the Feather is mounted.

## Stage 3: Assemble The 7-Segment FeatherWing Itself

Do this before soldering anything onto the Feather. The 7-segment FeatherWing
often comes as a FeatherWing PCB/backpack plus the LED display module. The LED
module must be soldered onto the FeatherWing PCB before the Feather can drive
it. Adafruit's assembly guide is here:
`https://learn.adafruit.com/adafruit-7-segment-led-featherwings/assembly`.

1. Unplug USB. Leave the LiPo disconnected.
2. Keep the Feather set aside. You are only working on the display FeatherWing.
3. If the LED display module is already soldered to the FeatherWing PCB, inspect
   the joints and skip to Stage 4.
4. Prepare the 12-pin and 16-pin male header strips for the FeatherWing:
   - Cut them to length if needed.
   - Put the long pins down into a breadboard so the short pins point up.
   - Place the FeatherWing PCB over the short pins.
   - Solder one corner pin on each row, confirm the PCB sits flat, then solder
     all remaining header pins.
5. Align the LED display module on the FeatherWing PCB:
   - Match the decimal point dots to the silkscreen; they should be on the
     bottom side indicated by the board.
   - Do not install the display upside down.
6. Solder the LED display module to the FeatherWing PCB:
   - Go slowly, one pin at a time.
   - Clip each display leg short after soldering if it is in the way.
7. Inspect the FeatherWing:
   - No solder bridges between adjacent display pins.
   - No solder bridges between adjacent header pins.
   - Display module is flat and correctly oriented.

## Stage 4: Solder Feather Stacking Headers And Install The Display

This step makes the display plug cleanly into the Feather while leaving the
stacking-header tails accessible underneath for later pod wiring.

Do not solder the display FeatherWing directly to the Feather. The Feather gets
the stacking headers; the assembled display FeatherWing plugs into the sockets
on top. The male tails underneath the Feather remain usable connection points
for `D6`, `BAT`, `GND`, `EN`, and any other signals needed later.

1. Unplug USB. Leave the LiPo disconnected.
2. Solder the stacking headers onto the Feather:
   - Put the female sockets on the component/top side of the Feather.
   - The male tails pass down through the Feather holes.
   - Solder from the underside of the Feather.
   - Start with one corner pin on each row, check that both headers are straight,
     then solder the remaining pins.
3. Plug the assembled 7-segment FeatherWing into the Feather's top sockets.
   Align both rows; do not offset by one pin. The display should sit above the
   Feather, LED side up.
4. Plug USB back in.
5. Copy `CIRCUITPY/bringup/02_i2c_scan.py` to the Feather as `code.py`.

Success: the serial console reports an I2C address `0x70`.

Then copy `CIRCUITPY/bringup/03_display_test.py` to the Feather as `code.py`.

Success: the display shows `8888`, then a counting number.

If it fails:
- Power off and check the display is not shifted by one pin.
- Power off and confirm the LED display module is not upside down.
- Reflow any dull or cracked header joints.
- Run the I2C scanner again. No `0x70` means the display is not electrically connected.

## Stage 5: Connect And Test The GPS

1. Unplug USB.
2. Plug one end of the STEMMA QT cable into the Feather's STEMMA QT port.
3. Plug the other end into the PA1010D GPS.
4. Place the GPS with the ceramic antenna facing upward.
5. Plug USB back in.
6. Copy `CIRCUITPY/bringup/02_i2c_scan.py` to the Feather as `code.py`.

Success: the scanner should show `0x70` for the display and `0x10` for the GPS.

Then copy `CIRCUITPY/bringup/04_gps_test.py` to the Feather as `code.py`.

Success: the serial console prints fix status and satellite count once per
second. Take the GPS outdoors for the first real fix; the first fix can take a
few minutes. Once fixed, it prints latitude/longitude and speed in knots.

If it fails:
- Reseat both ends of the STEMMA QT cable.
- Confirm the GPS antenna side is facing up.
- Move outdoors, away from buildings and metal surfaces.
- Add the CR1220 coin cell later to improve warm-start behavior.

## Stage 6: Confirm Battery Charging

Do this before the LEDs, while the current draw is still small.

The battery for this build is the Adafruit 3.7V 2000mAh LiPo, PID 2011. It uses
Adafruit-standard JST-PH polarity and should plug straight into the Feather, but
do the polarity check anyway before first power. Plugging in a reversed-polarity
battery will damage the Feather's charger IC, the battery, or both. This is the
most common way people kill Feathers. Do not skip the check.

1. Unplug USB.
2. Verify the battery polarity before plugging it into the Feather:
   - Look at the Feather RP2040 silkscreen next to the JST-PH battery socket.
     It marks `+` and `-` for the two contacts. On the Feather RP2040, `+` is
     the contact closer to the USB-C port; `-` is the outboard contact.
   - With the battery still unplugged, take a photo or note which colored wire
     of the battery enters which side of the JST housing. Do not trust the
     wire color alone — confirm electrically in the next step.
   - Set a multimeter to DC volts (20 V range). Carefully probe the bare metal
     of each contact through the slots in the battery's JST-PH connector:
     red probe on the contact you think is `+`, black on the contact you think
     is `-`.
       - A positive reading (~3.7-4.2 V) means the wire on your red-probe side
         is `+`. Confirm that wire lines up with the Feather's `+` silkscreen
         mark when the connector is oriented to plug in.
       - A negative reading means the battery's `+` and `-` are swapped
         relative to where the Feather expects them.
   - If swapped:
       - Depress the tiny barb on each metal contact with a pin or fine
         tweezers and slide the contact out the back of the JST housing.
       - Swap the two contacts so they sit in the opposite positions.
       - Push them back in until they click and gently tug each wire to
         confirm it's seated.
       - Re-check with the multimeter before plugging into the Feather.
   - Only proceed once the multimeter confirms `+` on the battery aligns with
     `+` on the Feather silkscreen.
3. Put the Feather on a non-conductive surface.
4. Plug the LiPo into the Feather JST-PH battery connector.
5. Plug USB back in.
6. Confirm the Feather charge LED turns on or indicates charging.
7. Let it charge for a few minutes and confirm the LiPo does not get hot, puff,
   or smell odd.
8. Leave `03_display_test.py` on the board, or copy it back to the board as
   `code.py`, so the display gives you a visible battery-power indicator.
9. Unplug USB and confirm the Feather can boot from battery by watching the
   display counter.

Success: the board runs from USB, charges the LiPo, and also runs from battery.

Stop immediately if the battery heats up, swells, smokes, smells odd, or the
connector polarity does not match the Feather silkscreen after the multimeter
check.

## Stage 7: Test The LED Lane

This v2 uses a single 10-pixel lane, so this one stage is the whole LED bring-up
— there is no separate four-lane stage anymore. Do this on the bench before
bonding the lane to the armband.

1. Unplug USB and LiPo.
2. Cut one 10-pixel lane from the BTF-LIGHTING WS2812B NeoPixel strip.
3. Find the `DIN`, `+`, and `GND` pads. Follow the strip's data arrows; wire
   into the `DIN` end (the `DOUT` end stays unused).
4. Wire Feather `D6` through the 470 ohm resistor (a single 330 ohm is fine —
   300-500 ohm acceptable) to strip `DIN`. The resistor sits in series on the
   data line: `D6` -> resistor leg 1, resistor leg 2 -> `DIN`.
5. Wire strip `GND` to Feather `GND`.
6. For this test, wire strip `+` to Feather `BAT` or to the planned switched LED
   power line.
7. Add the 100uF capacitor across strip `+` and `GND`, observing polarity.
8. Plug in the LiPo, then USB.
9. Copy `CIRCUITPY/bringup/05_one_lane_neopixel_test.py` to the Feather as `code.py`.

Success: the 10-pixel lane shows a low-brightness chasing pattern.

If it fails:
- Check that data goes into `DIN`, not `DOUT`.
- Check that LED ground and Feather ground are connected.
- Check capacitor polarity.
- Keep brightness low during testing.

> Single lane means no serpentine and no lane-to-lane data joints — the part
> that was the hardest soldering in the four-lane plan is simply gone. If you
> later want more lanes, the firmware only needs `LANE_COUNT`, `PIXELS_PER_LANE`,
> and `LANE_REVERSED` changed in `code.py`.

## Stage 8: Switch Test

Only add the DPDT switch after the Feather, display, GPS, battery, and the LED
lane have all worked independently.

1. Unplug USB and LiPo.
2. Wire switch pole 1:
   - Common lug to Feather `EN`.
   - OFF throw to Feather `GND`.
   - ON throw left unconnected.
3. Wire switch pole 2:
   - Common lug to LED `+` (the hardwired conductor to the lane).
   - ON throw to Feather `BAT`.
   - OFF throw left unconnected.
4. Plug in LiPo.
5. Turn switch ON: Feather and LEDs should power.
6. Turn switch OFF: Feather and LEDs should turn off.
7. Plug in USB with LiPo still connected and confirm charging still works.

Success: the switch turns the wearable off, but USB-C charging still works
because the LiPo remains connected to the Feather charger.

## Stage 9: Full Firmware

After every staged test passes:

1. Copy this repo's `CIRCUITPY/code.py` to the Feather as `code.py`.
2. Power on.
3. Confirm boot behavior:
   - Display shows `8888`.
   - LEDs show a blue sweep.
   - Display shows `----` while waiting for GPS.
   - LEDs show an amber no-fix wave.
4. Take the setup outdoors.
5. Confirm GPS fix and mph display.

Do not put the boards in the pod until this stage works on the bench.

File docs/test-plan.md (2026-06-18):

# Test Plan

## Bench Tests

- USB boot: Feather appears as CIRCUITPY, runs `code.py`, and shows boot pattern.
- Battery boot: unplug USB, turn switch on, and confirm display/LED startup.
- Switch off: display, GPS, and LEDs all turn off.
- USB-C charging: with LiPo plugged in, USB-C powers the charger and charge LED is visible.
- I2C display: display shows `8888` at boot and `----` while waiting for GPS.
- GPS: PA1010D gets an outdoor fix with the antenna facing up.
- LED lane: all 10 pixels respond; the comet/wave runs cleanly down the lane.
- Brownout check: at configured brightness, no random resets or flicker.

## Intentional State Tests

- No GPS fix: cover/start indoors and confirm amber wave + `----`.
- Normal running/walking: go outdoors and confirm numeric mph + fixed-rate rainbow wave.
- GPS stale/lost: block GPS sky view after a fix and confirm yellow pulse + `----`.
- Caught code error: temporarily raise an exception after setup and confirm red flashing + `Err`.

## Wear Tests

- Pod does not slide on the armband.
- Hardwired pod-to-lane cable is strain-relieved; a tug on the armband reaches the grommet clamp, not the solder joints.
- The LED lane does not sharply bend at solder pads.
- No exposed copper, solder, pins, or sharp enclosure edges touch skin/clothing.
- LiPo is not compressed, bent, punctured, hot, or rubbing against hardware.
- Charging works in place via USB-C with the pod mounted on the armband (the pod is hardwired to the lane; it does not detach for charging).

## Acceptance Criteria

- Runtime reaches at least 90 minutes with normal LED brightness.
- Display remains readable while walking/running outdoors.
- GPS speed is plausible compared with a phone/watch.
- All status patterns are distinguishable to an adult helper.
- The kid can put on/remove the armband without managing loose wires.

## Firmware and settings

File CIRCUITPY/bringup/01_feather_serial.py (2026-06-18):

"""Stage 1 bring-up: Feather alone.

Copy this file to CIRCUITPY/code.py. Open the serial console. You should see a
counter print once per second. If the board exposes board.LED, it will blink.
"""

import time

import board
import digitalio


led = None
led_pin = getattr(board, "LED", None)
if led_pin is not None:
    led = digitalio.DigitalInOut(led_pin)
    led.direction = digitalio.Direction.OUTPUT

count = 0
while True:
    print("Feather RP2040 alive:", count)
    if led is not None:
        led.value = not led.value
    count += 1
    time.sleep(1)

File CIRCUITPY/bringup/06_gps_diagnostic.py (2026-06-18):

"""GPS diagnostic: prove the module is talking, then watch satellites climb.

Copy to CIRCUITPY/code.py and open the serial console. Take it outdoors with the
ceramic antenna (the square metal patch) facing straight up at open sky.

How to read the output:
- "0x10 on bus: True"            -> GPS is wired and responding on I2C.
- "0x10 on bus: False"          -> GPS not connected (check STEMMA QT / SDA-SCL).
- raw NMEA lines printing        -> the module IS sending data.
- "sats in view: N" climbing    -> antenna sees sky; a fix is coming.
- sats stuck at 0 for minutes    -> antenna blocked, indoors, or antenna fault.
"""

import time

import adafruit_gps
import board
import busio


def make_i2c():
    try:
        return board.I2C()
    except AttributeError:
        return busio.I2C(board.SCL, board.SDA)


i2c = make_i2c()

# 1) Is the GPS even on the bus?
while not i2c.try_lock():
    pass
found = i2c.scan()
i2c.unlock()
print("I2C devices:", [hex(a) for a in found])
print("0x10 on bus:", 0x10 in found, " (GPS)")
print("0x70 on bus:", 0x70 in found, " (display)")

gps = adafruit_gps.GPS_GtopI2C(i2c, debug=False)
# Output GGA (fix + sats) and RMC (speed), once per second.
gps.send_command(b"PMTK314,0,1,0,1,0,0,0,0,0,0,0,0,0,0,0,0,0,0,0")
gps.send_command(b"PMTK220,1000")

last_print = 0
saw_any_sentence = False

while True:
    gps.update()
    now = time.monotonic()

    # nmea_sentence holds the most recent raw sentence the parser accepted.
    sentence = getattr(gps, "nmea_sentence", None)
    if sentence and not saw_any_sentence:
        saw_any_sentence = True
        print("FIRST RAW NMEA SEEN:", sentence)

    if now - last_print >= 1.0:
        last_print = now
        print(
            "talking:", saw_any_sentence,
            "| fix:", gps.has_fix,
            "| sats in view:", gps.satellites,
        )
        if sentence:
            print("   raw:", sentence)
        if gps.has_fix:
            print("   lat/lon:", gps.latitude, gps.longitude,
                  "| speed_knots:", gps.speed_knots)

    time.sleep(0.1)

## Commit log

2026-06-18 clean up for public consumption
    [base.3mf, base.stl, base_plate.stl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]
2026-06-19 Enhance README with LED strip description
    Expanded project description to include LED strip details.
2026-10-13 Raise GPS fix rate to 2 per second
    On-device timing (2026-10-12) showed the Feather drains ~285 B/s from the
    PA1010D at the current polling (gps.update() every 0.1 s, 20 ms timeout).
    RMC-only at 1 fix/s is ~72 B/s, so 2 fixes/s (~144 B/s) fits comfortably and
    roughly halves how stale the displayed speed can be.
    Speed samples were keyed on whole seconds (timestamp_utc), which would drop
    every second fix at 2 Hz; key on the RMC time field with fractional seconds.
    Note: ZERO_CONFIRM_SAMPLES counts fixes, so the drop to 0.00 now takes 1 s
    instead of 2 s.
2026-10-13 Document GPS rate, stationary-speed filtering and cold-start time
    Record why the firmware requests RMC only at 2 fixes/s, how the PA1010D's
    static-navigation filter and the firmware deadband split the job of zeroing
    stationary speed, and what to expect at power-on without the backup coin cell.
    All figures are from on-device measurements in October 2026.
